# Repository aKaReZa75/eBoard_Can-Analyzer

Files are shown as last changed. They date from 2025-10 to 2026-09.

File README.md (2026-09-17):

# eBoard Can BUS Analyzer

This project is a **custom STM32-based CAN analyzer** designed to capture, monitor, and analyze **CAN BUS** traffic using **SavvyCAN** or any other compatible PC software.
It supports both **Classical CAN (2.0A/B)** and **CAN FD**, making it a flexible and powerful tool for vehicle diagnostics, reverse engineering, and data logging applications.

> [!NOTE]
This design is **based on the open-source Canable 2.0 project**, available at [https://canable.io/](https://canable.io/)

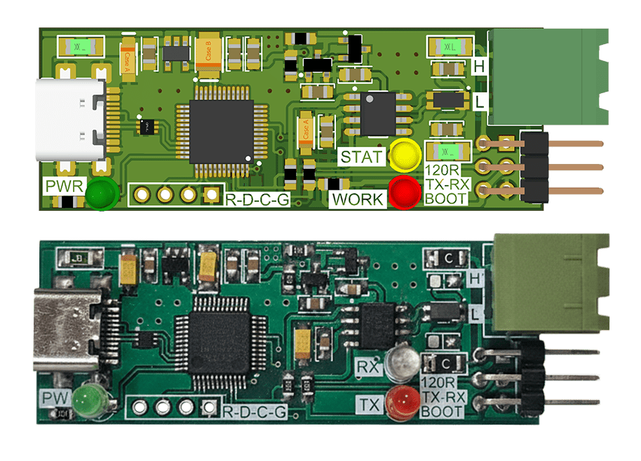
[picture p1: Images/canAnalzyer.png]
canAnalzyer


<table>
  <tr>
  <td valign="top">
  
  > [!TIP]  
  > If you're looking to better understand how to navigate and use my GitHub repositories — including exploring their structure, downloading or cloning projects, submitting issues, and asking questions,  
  > everything you need is clearly explained in this video:  
  > [aKaReZa 95 - Programming, Git - PART B](https://youtu.be/zYiUItVFRqQ)  
  > Make sure to check it out!
  
  </td>
    <td width="360" valign="middle" style="padding: 0;">
      <a href="https://youtu.be/zYiUItVFRqQ">
       aKaReZa 95 - Programming, Git - PART B Thumbnail
      </a>
    </td>
  </td>
  </tr>

<tr>
  <td valign="top">
  
  > [!IMPORTANT]
  > Begin your embedded systems journey with clarity and purpose. This episode outlines a structured roadmap for mastering microcontrollers, communication protocols, hardware design, and project development.  
  > Learn how to choose your specialization, follow curated playlists, and engage effectively with the community—ideal for learners seeking a scalable, goal-driven path into embedded engineering.  
  > [aKaReZa 124 – Embedded Systems Roadmap](https://youtu.be/3QYfv7A7aMc)  
  > Watch it now to kickstart your journey!
  
  </td>
  <td width="360" valign="middle" style="padding: 0;">
    <a href="https://youtu.be/3QYfv7A7aMc">
      aKaReZa 124 – Embedded Systems Roadmap Thumbnail
    </a>
  </td>
</tr>

  <tr>
  <td colspan="3">

  > [!CAUTION]
  > It is absolutely critical that you carefully read every single word of this document, line by line, to ensure you don't miss any details. Nothing can be overlooked.
      
  </td>
  </tr>  
</table>

##  Key Features
* **Dual CAN Protocol Support**
  Fully compatible with **CAN 2.0A/B** and **CAN FD** standards.

* **USB Interface with DFU Support**
  Built-in **DFU (Device Firmware Upgrade)** mode allows you to easily update firmware via USB — no external programmer needed.

* **Hardware Termination Control**
  Includes a dedicated **jumper** to enable or disable the **120 Ω termination resistor**, allowing flexible connection to different CAN networks.

* **Direct CAN TX/RX Monitoring Pins**
  The **TX** and **RX** lines of the CAN transceiver are **broken out** for use with a **logic analyzer**, enabling low-level signal observation and debugging.

* **Robust EMI Protection**
  The board integrates **EMI filters**, **common-mode chokes**, and **TVS diodes** on both the **USB** and **CAN** interfaces — ensuring reliable operation in noisy automotive environments.

* **Software Compatibility**
  Fully supported by **SavvyCAN**, **candleLight**, and any **SocketCAN-compatible** toolset on Windows, Linux, or macOS.

## Typical Use Cases
* Sniffing and analyzing automotive CAN frames
* Reverse-engineering vehicle signals (speed, RPM, etc.)
* Logging CAN data for diagnostics or visualization
* Testing and validating CAN-based ECUs and sensors
* Educational and research projects in automotive communication

## Firmware Recommendation
For best performance, it’s recommended to flash the **`CANable_2.0_SLCAN_FD_7-7-22.bin`** firmware onto the board.
You can program it using an external **programmer** (e.g., ST-Link) or update it directly through the **DFU bootloader** using standard DFU utilities or GUI tools.
This firmware provides full support for **CAN FD** and ensures stable communication with **SavvyCAN**, **Cangaroo**, and other compatible CAN analysis software.

## Technical Highlights
| Feature | Description |
| --- | --- |
| MCU | STM32G431C8T6 |
| CAN Support | CAN 2.0A/B and CAN FD |
| USB Mode | Full-Speed USB 2.0 |
| Firmware Update | DFU mode over USB |
| Software Support | Savvycan/Cangaroo |
| Termination | Selectable 120 Ω via jumper |
| Protection | EMI filter, TVS diodes, common-mode choke |
| Monitoring | TX/RX breakout for logic analyzer |
| Compatible Software | SavvyCAN, SocketCAN, BusMaster, etc. |
| PCB Design Software | Altium  V24.2.2 |
| PCB Layers | 2-Layer FR4 |

# 🔗 Resources
  Here you'll find a collection of useful links and videos related to this topic.  
  
> [!TIP]
> The resources are detailed in the sections below.  
> To access any of them, simply click on the corresponding blue link.

- [Altium Library](https://github.com/aKaReZa75/Altium-Library)  
  ---  
   All PCB designs across all repositories and projects are built using this Altium Designer component library. It contains a wide range of verified footprints, schematic symbols, and 3D models, ensuring consistency and accuracy in PCB designs. If you're working on a new PCB, using this library will save you time and minimize errors.

- [PCB & Electronics Design Training](https://github.com/aKaReZa75/PCB)  
  ---  
  This repository is dedicated to **learning PCB design and electronics from scratch**. It covers everything from circuit theory to practical PCB layout techniques, including routing strategies, best practices, and component placement. Whether you're a beginner or an experienced designer, this resource will help you **improve your PCB design skills and create professional-quality boards**.

- [Shopping Link](./ShoppingLink.md)  
  ---
  This document provides links to trusted suppliers where you can purchase all the essential components for this project, ensuring quality and reliability.

- [SavvyCAN](https://github.com/collin80/SavvyCAN)
  ---
  A powerful **cross-platform CAN bus capture and reverse engineering tool** built with **Qt/C++**.
  SavvyCAN supports a wide range of CAN interfaces (SocketCAN, PeakCAN, Vector, J2534, etc.) and allows simultaneous connection to multiple buses.
  It includes features for **graphing, decoding with DBC files, UDS scanning**, and analyzing complex CAN traffic efficiently.

- [Cangaroo](https://github.com/normaldotcom/cangaroo)
  ---
  An open-source **CAN bus analyzer** supporting **transmit/receive of standard and FD frames**, as well as **DBC decoding** for incoming data.
  It works seamlessly on **Windows** and **Linux** with any **CANable** device running **Candlelight** or **SLCAN** firmware.
  Cangaroo provides advanced features like DBC decoding, periodic frame transmission, and multi-interface auto-detection on startup.

## Project Videos

```plaintext
CAN BUS Analyzer
└─ [aKaReZa 141 - eBoard, CAN Analyzer]
      ├─ Design — Hardware architecture and schematic review.
      ├─ Assembly — PCB soldering and device bring-up.
      ├─ Firmware — Programming and initial configuration.
      ├─ Interface — Pinout and CAN connectivity.
      ├─ Analysis — Using SavvyCAN and Congroo.
      └─ Applications — CAN monitoring, debugging, and diagnostics.
```

<table style="border-collapse: collapse;">
  <tr style="background-color: #f9f9f9;">
    <td valign="top" style="padding: 0 10px;">
      <h3 style="margin: 0;">
        <a href="https://youtu.be/rj74_Sh1n9M">aKaReZa 141 – eBoard, CAN Analyzer</a>
      </h3>
      <p style="margin: 8px 0 0;">
        Learn how to design, assemble, and use a complete <strong>CAN Analyzer</strong> from scratch. This episode covers the hardware architecture, schematic review, PCB assembly, firmware programming, device pinout, and integration with tools like <strong>SavvyCAN</strong> and <strong>Congroo</strong> for CAN bus monitoring and analysis. A practical introduction for anyone interested in CAN network development, debugging, and diagnostics.
      </p>
    </td>
    <td width="360" valign="top">
      <a href="https://youtu.be/rj74_Sh1n9M">
        aKaReZa 43 – PCB, USB to TTL Thumbnail
      </a>
    </td>
  </tr>
</table>

# 💻 How to Use Git and GitHub
To access the repository files and save them on your computer, there are two methods available:
1. **Using Git Bash and Cloning the Repository**
   - This method is more suitable for advanced users and those familiar with command-line tools.
   - By using this method, you can easily receive updates for the repository.

2. **Downloading the Repository as a ZIP file**
   - This method is simpler and suitable for users who are not comfortable with command-line tools.
   - Note that with this method, you will not automatically receive updates for the repository and will need to manually download any new updates.

## Clone using the URL.
First, open **Git Bash** :
-  Open the folder in **File Explorer** where you want the library to be stored.
-  **Right-click** inside the folder and select the option **"Open Git Bash here"** to open **Git Bash** in that directory.

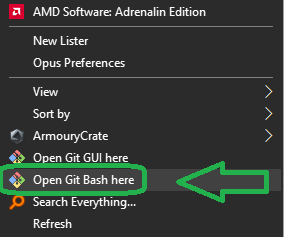
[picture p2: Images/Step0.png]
open Git Bash


> [!NOTE] 
> If you do not see the "Open Git Bash here" option, it means that Git is not installed on your system.  
> You can download and install Git from [this link](https://git-scm.com/downloads).  
> For a tutorial on how to install and use Git, check out [this video](https://youtu.be/BsykgHpmUt8).
  
-  Once **Git Bash** is open, run the following command to clone the repository:

 ```bash
git clone https://github.com/aKaReZa75/eBoard_Can-Analyzer.git
```
- You can copy the above command by either:
- Clicking on the **Copy** button on the right of the command.
- Or select the command text manually and press **Ctrl + C** to copy.
- To paste the command into your **Git Bash** terminal, use **Shift + Insert**.

Clone the Repository

- Then, press Enter to start the cloning operation and wait for the success message to appear.

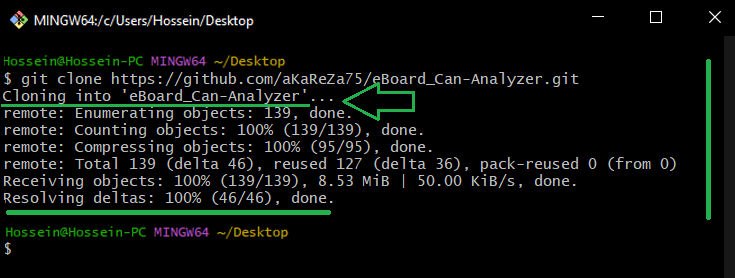
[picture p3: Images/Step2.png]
Open the Library File


> [!IMPORTANT]
> Please keep in mind that the numbers displayed in the image might vary when you perform the same actions.  
> This is because repositories are continuously being updated and expanded. Nevertheless, the overall process remains unchanged.

> [!NOTE]
> Advantage of Cloning the Repository:  
> - **Receiving Updates:** By cloning the repository, you can easily and automatically receive new updates.  
> - **Version Control:** Using Git allows you to track changes and revert to previous versions.  
> - **Team Collaboration:** If you are working on a project with a team, you can easily sync changes from team members and collaborate more efficiently.  

## Download Zip
If you prefer not to use Git Bash or the command line, you can download the repository directly from GitHub as a ZIP file.  
Follow these steps:  
1. Navigate to the GitHub repository page and Locate the Code button:
   - On the main page of the repository, you will see a green Code button near the top right corner.

2. Download the repository:
   - Click the Code button to open a dropdown menu.
   - Select Download ZIP from the menu.

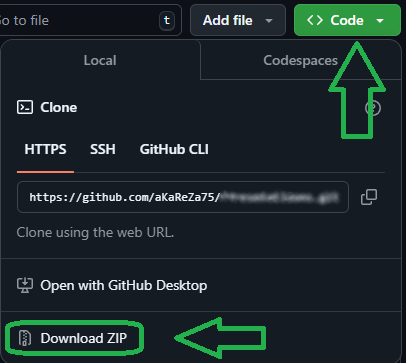
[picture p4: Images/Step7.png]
Download Zip
    

3. Save the ZIP file:
   - Choose a location on your computer to save the ZIP file and click Save.

4. Extract the ZIP file:
   - Navigate to the folder where you saved the ZIP file.
   - Right-click on the ZIP file and select Extract All... (Windows) or use your preferred extraction tool.
   - Choose a destination folder and extract the contents.

5. Access the repository:
   - Once extracted, you can access the repository files in the destination folder.

> [!IMPORTANT]
> - No Updates: Keep in mind that downloading the repository as a ZIP file does not allow you to receive updates.    
>   If the repository is updated, you will need to download it again manually.  
> - Ease of Use: This method is simpler and suitable for users who are not comfortable with Git or command-line tools.

# 📝 How to Ask Questions
If you have any questions or issues, you can raise them through the **"Issues"** section of this repository. Here's how you can do it:  

1. Navigate to the **"Issues"** tab at the top of the repository page.  

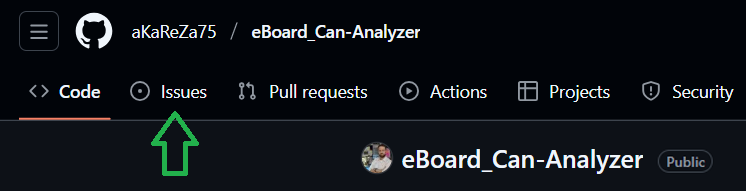
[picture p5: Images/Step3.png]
Issues
  

2. Click on the **"New Issue"** button.  
   
  New Issue

3. In the **Title** field, write a short summary of your issue or question.  

4. In the "Description" field, detail your question or issue as thoroughly as possible. You can use text formatting, attach files, and assign the issue to someone if needed. You can also use text formatting (like bullet points or code snippets) for better readability.  

5. Optionally, you can add **labels**, **type**, **projects**, or **milestones** to your issue for better categorization.  

6. Click on the **"Submit new issue"** button to post your question or issue.
   
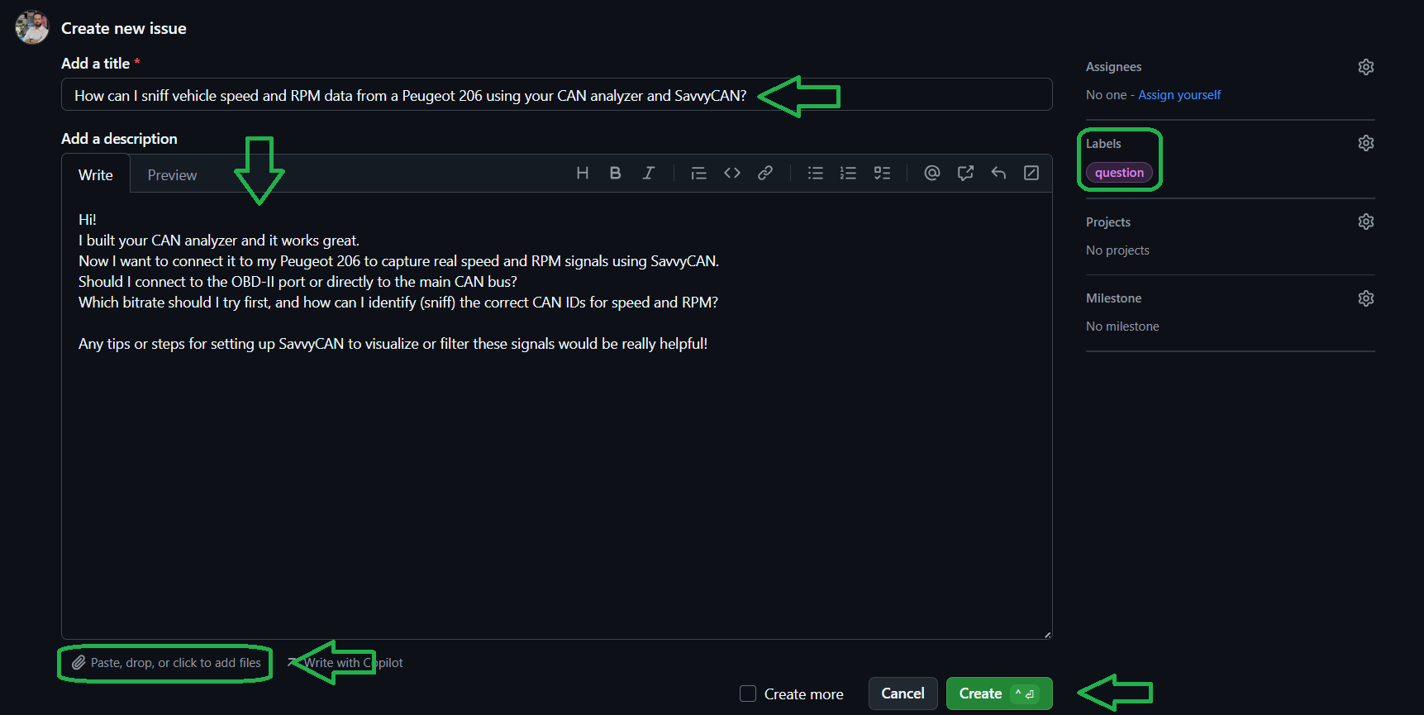
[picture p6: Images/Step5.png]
Submeet New Issue
  

I will review and respond to your issue as soon as possible. Your participation helps improve the repository for everyone!  

> [!TIP]
> - Before creating a new issue, please check the **"Closed"** section to see if your question has already been answered.  
>   Closed section  
> - Write your question clearly and respectfully to ensure a faster and better response.  
> - While the examples provided above are in English, feel free to ask your questions in **Persian (فارسی)** as well.  
> - There is no difference in how they will be handled!  

> [!NOTE]
> Pages and interfaces may change over time, but the steps to create an issue generally remain the same.

# 🤝 Contributing to the Repository
To contribute to this repository, please follow these steps:
1. **Fork the Repository**  
2. **Clone the Forked Repository**  
3. **Create a New Branch**  
4. **Make Your Changes**  
5. **Commit Your Changes**  
6. **Push Your Changes to Your Forked Repository**  
7. **Submit a Pull Request (PR)**  

> [!NOTE]
> Please ensure your pull request includes a clear description of the changes you’ve made.
> Once submitted, I will review your contribution and provide feedback if necessary.

# 🌟 Support Me
If you found this repository useful:
- Subscribe to my [YouTube Channel](https://www.youtube.com/@aKaReZa75).
- Share this repository with others.
- Give this repository and my other repositories a star.
- Follow my [GitHub account](https://github.com/aKaReZa75).

# 📜 License
This project is licensed under the GPL-3.0 License. This license grants you the freedom to use, modify, and distribute the project as long as you:
- Credit the original authors: Give proper attribution to the original creators.
- Disclose source code: If you distribute a modified version, you must make the source code available under the same GPL license.
- Maintain the same license: When you distribute derivative works, they must be licensed under the GPL-3.0 too.
- Feel free to use it in your projects, but make sure to comply with the terms of this license.
  
# ✉️ Contact Me
Feel free to reach out to me through any of the following platforms:
- 📧 [Email: aKaReZa75@gmail.com](mailto:aKaReZa75@gmail.com)
- 🎥 [YouTube: @aKaReZa75](https://www.youtube.com/@aKaReZa75)
- 💼 [LinkedIn: @akareza75](https://www.linkedin.com/in/akareza75)

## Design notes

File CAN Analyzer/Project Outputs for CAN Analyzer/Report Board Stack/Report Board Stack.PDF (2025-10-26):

# Board Stack Report

Stack Up | Layer Stack
Layer | Board Layer Stack | Name | Material | Thickness | Constant | Dk | Coverlay expansion | Orientation | Copper Orientation
1 | | Top Overlay | | 0mm
2 | | Top Solder | Solder Resist | 0.01016mm | 3.5 | 3.5 0mm
3 | | Top Layer | | 0.03556mm | | | | BodyUp | Above
4 | | Dielectric 1 | FR-4 | 1.5mm | 4.8 | 4.8
5 | | Bottom Layer | | 0.03556mm | | | | BodyDown | Below
6 | | Bottom Solder | Solder Resist | 0.01016mm | 3.5 | 3.5 0mm
7 | | Bottom Overlay | | 0mm
| Height : 1.59144mm

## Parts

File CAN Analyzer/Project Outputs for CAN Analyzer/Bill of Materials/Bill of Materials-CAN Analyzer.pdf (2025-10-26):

Comment | Description | Designator | Footprint | LibRef | Quantity | Value | Type | Rating | Inflow | Package
100n | Bipolar ceramic capacitor SMD | C2, C4, C6, C7, C14, C15 | CAP 0805/2012 | Cap_Multi_SMD_100nF _0805 | 6 | 100n | MultiLayer | 50V | inflow? | 0805
10u | Bipolar ceramic capacitor SMD | C13 | CAP 0805/2012 | Cap_Multi_SMD_0805 | 1 | 10u | MultiLayer | Rating? | inflow? | 0805
47p | Bipolar ceramic capacitor SMD | C16, C17 | CAP 0805/2012 | Cap_Multi_SMD_0805 | 2 | 47p | MultiLayer | Rating? | inflow? | 0805
4u7 | Tantalum Capacitor,TAJ Series-SMD | C3 | SMT_C_Tantalum_A | Cap_Tantalum | 1 | 4u7 | Tantalum | 6.3V | inflow? | SMD-A
10u | Tantalum Capacitor,TAJ Series-SMD | C1 | SMT_C_Tantalum_A | Cap_Tantalum | 1 | 10u | Tantalum | 6V3 | inflow? | Package?
10u | Tantalum Capacitor,TAJ Series-SMD | C5 | SMT_C_Tantalum_B | Cap_Tantalum | 1 | 10u | Tantalum | 6V3 | inflow? | Package?
3x2 | Header, dual row, 6 pin | J3 | HDR_THT_3x2M_2.54m m_RA | Con_MPH_3x2_V_THT_ 2.54 | 1 | 3x2 | Type? | Rating? | 7152 | Package?
4b | Header, single row, 4 pin | J2 | HDR_THT_4M_2.54mm | Con_MPH_4x1_V_THT_ 2.54 | 1 | 4b | Vertical | 4x1 | 7152 | Dip
2'Pin | Power Connector 2'Pin | P1 | Phoenix_2PIN_RA_P5.0 8mm | Con_Power_2 | 1 | 2'Pin | Type? | Rating? | inflow? | Package?
16P | USB C Female Connector | J1 | USBC_SMD_16_USB41 10 - Extended | Con_USB_C_16P | 1 | 16P | C | Rating? | inflow? | SMD
TJA1051T-3 | High-Speed CAN Transceiver That Provides an Interface Between a CAN Protocol Controller and The Physical Two-Wire CAN Bus. | U1 | SO8_narrow_M | IC_Converter_TJA1051 T-3 | 1 | TJA1051T-3 | CAN-FD | 5Mbits/s | inflow? | SOIC-8
STM32G431C8T6 | 32-Bit mircrocontroller | U3 | LQFP48_N | IC_MCU_STM32G431C 8T6 | 1 | STM32G431C8T6 | Microcontroller | CORTEX-M4 | inflow? | LQFP48
3.3V | Fixed LDO Voltage Regulator 3.3V 300mA SOT-23-5 | U2 | SOT95P280X130-5N | IC_Reg_TLV74333PDBV R | 1 | 3.3V | LDO | 300m | inflow? | SOT-23-5
Value? | 2 Line Common Mode Choke Surface Mount 90 Ohms @ 100 MHz 370mA DCR 300mOhm | L1 | FIL_DLW31SN900SQ2L _Extended | Ind_EMI_DLW31SN900 SQ2L | 1 | Value? | Type? | Rating? | inflow? | Package?
ECMF02-2AMX6 | Common Mode Filter with ESD Protection for USB 2.0 and MIPI D-PHY/MDDI Interface | L2 | SON50P150X170X55-6N | Ind_EMI_ECMF02-2AMX6 | 1 | ECMF02-2AMX6 | EMI Filters | 2.5R | | QFN-6
250m | Short circiut protection | F3 | 1206_F | Other_Elec_Fuse_SMD | 1 | 250m | Fast | Rating? | 0.5A | 1206
200m | SMD Resettable Fuses | F1, F2 | 1206_F | Other_Elec_PFUSE_SM D | 2 | 200m | Resettable | 24V | inflow? | 1206
1M | Resistor | R13 | RES 0805 (2012X06L) | Res_SMD_0805 | 1 | 1M | 10% | 0.125W | inflow? | 0805
4K7 | Resistor | R4, R5, R10, R14 | RES 0805 (2012X06L) | Res_SMD_0805 | 4 | 4K7 | 10% | 0.125W | inflow? | 0805
10K | Resistor | R9, R16 | RES 0805 (2012X06L) | Res_SMD_0805 | 2 | 10K | 10% | 0.125W | inflow? | 0805
22R | Resistor | R1, R2 | RES 0805 (2012X06L) | Res_SMD_0805 | 2 | 22R | 10% | 0.125W | inflow? | 0805
47K | Resistor | R11, R15 | RES 0805 (2012X06L) | Res_SMD_0805 | 2 | 47K | 10% | 0.125W | inflow? | 0805
100K | Resistor | R12 | RES 0805 (2012X06L) | Res_SMD_0805 | 1 | 100K | 10% | 0.125W | inflow? | 0805
120R | Resistor | R3 | RES 0805 (2012X06L) | Res_SMD_0805 | 1 | 120R | 1% | 0.125W | inflow? | 0805
330R | Resistor | R6, R7, R8 | RES 0805 (2012X06L) | Res_SMD_0805 | 3 | 330R | 10% | 0.125W | inflow? | 0805
BC817 | NPN General purpose Transistor | Q3, Q4 | SOT23_N | Semi_BJT_BC817 | 2 | BC817 | NPN | Rating? | inflow? | Package?
NPN | NPN General purpose Transistor | Q2 | SOT23_N | Semi_BJT_SS8050 | 1 | NPN | Type? | Rating? | 5256 | Package?
SM712 | TVS, ESD PROTECT, 2CH, 400W/17A PP, 7.5VBR, ±8KV ESDmin | D1 | SOT23_M | Semi_Diod_TVS_SM71 2 | 1 | SM712 | Type? | Rating? | inflow? | Package?
Green, 3'mm | LED | D3 | led-3mm | Semi_LED_Green_3 | 1 | Green, 3'mm | Type? | Rating? | 7145 | Package?
Red, 3'mm | LED | D4 | LED-3mm(RED) | Semi_LED_Red_3 | 1 | Red, 3'mm | Type? | Rating? | 7142 | Package?
Yellow | LED | D2 | LED-3mm_Yellow | Semi_LED_Yellow_3 | 1 | Yellow | LED | Rating? | 7145 | 3mm
P-Channel | P-Channel MOSFET | Q1 | SOT23_N | Semi_MOSFET_Si2301 DS | 1 | P-Channel | Type? | Rating? | 6208 | Package?

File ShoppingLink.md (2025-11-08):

# 📦 Components Purchase Links
This section provides a comprehensive list of components required for the "CAN BUS Analyzer" project.
Each item includes direct purchase links from reliable Iranian electronics suppliers, with recommended quantities for both essential needs and future prototyping.

## Capacitor
- [ ] [**Cap_0805 47p**](https://lionelectronic.ir/products/1952-0805CG470J500NT) Quantity: 4, Prefer: 25, Supplier: LionElectronic
- [ ] [**Cap_0805_100n**](https://lionelectronic.ir/products/2791-CL21B104KBCNNNC) Quantity: 8, Prefer: 25, Supplier: LionElectronic
- [ ] [**Cap_0805_10u**](https://lionelectronic.ir/products/3069-C2012X5R1H106K125AC) Quantity: 8, Prefer: 25, Supplier: LionElectronic
- [ ] [**Cap_Tantal_4.7u_6.3V_P**](https://lionelectronic.ir/products/2725-T55P475M6R3C0500) Quantity: 1, Prefer: 10, Supplier: LionElectronic 
- [ ] [**Cap_Tantal_10u_10V_A**](https://lionelectronic.ir/products/2046-TAJA106K010RNJ) Quantity: 3, Prefer: 10, Supplier: LionElectronic **(Instead of: Cap_Tantal_10u_6.3V_A)**

## Connector
- [ ] [**Male_PinHeader_Straight**](https://lionelectronic.ir/products/5356-PLS-2.54-1X40GF) Quantity: 0.1, Prefer: 1, Supplier: LionElectronic
- [ ] [**Male_PinHeader_Right_Double**](https://lionelectronic.ir/products/5359-DS1022-2X40R-1) Quantity: 0.1, Prefer: 1, Supplier: LionElectronic  
- [ ] [**Con_Phonix_2Pin**](https://lionelectronic.ir/products/6049-KF2EDGR%2BK-5.08-2P) Quantity: 2, Prefer: 5, Supplier: LionElectronic
- [ ] [**USB_Type_C_16_2**](https://lionelectronic.ir/products/4117-TYPE-C-16P-QTWT) Quantity: 1, Prefer: 4, Supplier: LionElectronic

## Integrated Circuit
- [ ] [**IC_STM32G431C8T6**](https://lionelectronic.ir/products/2774-STM32G431C8T6) Quantity: 1, Prefer: 3, Supplier: LionElectronic  
- [ ] [**Reg_TLV74333PDBVR**](https://lionelectronic.ir/products/2492-TLV74333PDBVR) Quantity: 1, Prefer: 3, Supplier: LionElectronic
- [ ] [**IC_TJA1051T/3,118**](https://lionelectronic.ir/products/5827-TJA1051T-3%2C118) Quantity: 1, Prefer: 5, Supplier: LionElectronic

## Other
- [ ] [**DLW31SN900SQ2L**](https://lionelectronic.ir/products/1500-DLW31SN900SQ2L) Quantity: 2, Prefer: 5, Supplier: LionElectronic
- [ ] [**ECMF02-2AMX6**](https://lionelectronic.ir/products/4373-ECMF02-2AMX6) Quantity: 2, Prefer: 5, Supplier: LionElectronic
- [ ] [**Fuse_1206_0.5A**](https://lionelectronic.ir/products/1891-JFC1206-0500FS-63V-0.5A) Quantity: 1, Prefer: 5, Supplier: LionElectronic  
- [ ] [**rFuse_1206_0.2A**](https://lionelectronic.ir/products/2259-1206L020YR) Quantity: 1, Prefer: 5, Supplier: LionElectronic

## Resistor
- [ ] [**Res_0805_22b**](https://lionelectronic.ir/products/1553-0805W8J0220T5E) Quantity: 3, Prefer: 25, Supplier: LionElectronic
- [ ] [**Res_0805_120R_1%**](https://lionelectronic.ir/products/1404-CR0805F81200G) Quantity: 2, Prefer: 25, Supplier: LionElectronic  
- [ ] [**Res_0805_330b**](https://lionelectronic.ir/products/1567-SER0805J330R) Quantity: 5, Prefer: 25, Supplier: LionElectronic
- [ ] [**Res_0805_1K**](https://lionelectronic.ir/products/1573-RS-05K102JT) Quantity: 3, Prefer: 25, Supplier: LionElectronic  
- [ ] [**Res_0805_4.7K**](https://lionelectronic.ir/products/1581-SER0805J4K7) Quantity: 4, Prefer: 25, Supplier: LionElectronic 
- [ ] [**Res_0805_10K**](https://lionelectronic.ir/products/1585-SCR0805J10K) Quantity: 2, Prefer: 25, Supplier: LionElectronic
- [ ] [**Res_0805_47K**](https://lionelectronic.ir/products/1593-SER0805J47K) Quantity: 2, Prefer: 25, Supplier: LionElectronic
- [ ] [**Res_0805_100K**](https://lionelectronic.ir/products/1474-RS-05K1003FT) Quantity: 2, Prefer: 25, Supplier: LionElectronic
- [ ] [**Res_0805_1M**](https://lionelectronic.ir/products/1609-0805W8J0105T5E) Quantity: 1, Prefer: 25, Supplier: LionElectronic

## Semiconductore
- [ ] [**Semi_BJT_BC817**](https://lionelectronic.ir/products/134-BC817-40) Quantity: 2, Prefer: 10, Supplier: LionElectronic
- [ ] [**Semi_Mosfet_Si2301**](https://www.javanelec.com/shop/product/17001/vishay/si2301ds-t1) Quantity: 7, Prefer: 25, Supplier: JavanElectronic
- [ ] [**Semi_Diod_TVS_SM712**](https://lionelectronic.ir/products/113-SM712.TCT) Quantity: 1, Prefer: 5, Supplier: LionElectronic 
- [ ] [**LED_3mm_Red**](https://lionelectronic.ir/products/3245-XL-304SURC) Quantity: 4, Prefer: 10, Supplier: LionElectronic
- [ ] [**LED_3mm_Green**](https://lionelectronic.ir/products/3244-XL-304UGC) Quantity: 4, Prefer: 10, Supplier: LionElectronic
- [ ] [**LED_3mm_Yellow**](https://lionelectronic.ir/products/3247-XL-304UYC) Quantity: 4, Prefer: 10, Supplier: LionElectronic

# 🌟 Support Me
If you found this repository useful:
- Subscribe to my [YouTube Channel](https://www.youtube.com/@aKaReZa75).
- Share this repository with others.
- Give this repository and my other repositories a star.
- Follow my [GitHub account](https://github.com/aKaReZa75).

# ✉️ Contact Me
Feel free to reach out to me through any of the following platforms:
- 📧 [Email: aKaReZa75@gmail.com](mailto:aKaReZa75@gmail.com)
- 🎥 [YouTube: @aKaReZa75](https://www.youtube.com/@aKaReZa75)
- 💼 [LinkedIn: @akareza75](https://www.linkedin.com/in/akareza75)

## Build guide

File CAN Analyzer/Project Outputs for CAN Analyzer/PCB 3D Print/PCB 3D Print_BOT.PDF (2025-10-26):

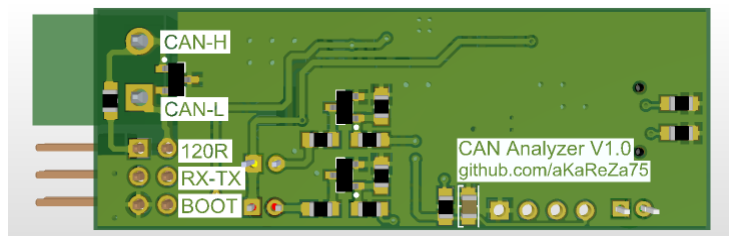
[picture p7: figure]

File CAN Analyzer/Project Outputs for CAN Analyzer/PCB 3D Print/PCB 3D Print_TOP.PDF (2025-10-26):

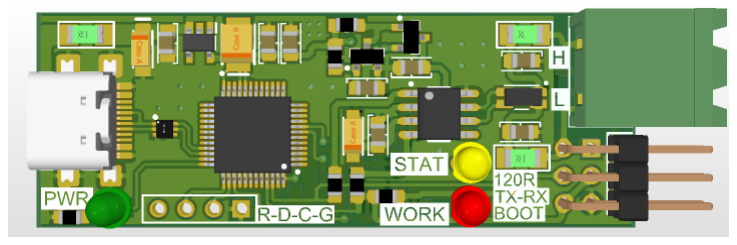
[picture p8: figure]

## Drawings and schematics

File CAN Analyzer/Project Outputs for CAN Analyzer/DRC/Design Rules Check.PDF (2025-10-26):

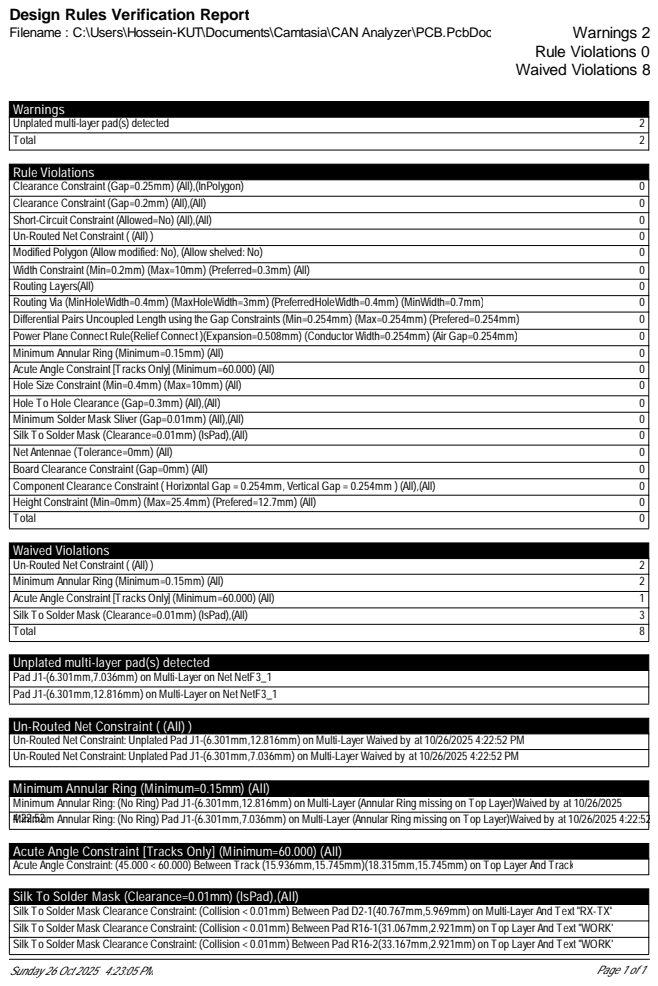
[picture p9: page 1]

Design Rules Verification Report

Unplated multi-layer pad(s) detected
Pad J1-(6.301mm,7.036mm) on Multi-Layer on Net NetF3_1
Pad J1-(6.301mm,12.816mm) on Multi-Layer on Net NetF3_1

Un-Routed Net Constraint ( (All) )
Un-Routed Net Constraint: Unplated Pad J1-(6.301mm,12.816mm) on Multi-Layer Waived by at 10/26/2025 4:22:52 PM
Un-Routed Net Constraint: Unplated Pad J1-(6.301mm,7.036mm) on Multi-Layer Waived by at 10/26/2025 4:22:52 PM

Minimum Annular Ring (Minimum=0.15mm) (All)
Minimum Annular Ring: (No Ring) Pad J1-(6.301mm,12.816mm) on Multi-Layer (Annular Ring missing on Top Layer)Waived by at 10/26/2025

M:2in2im:52um Annular Ring: (No Ring) Pad J1-(6.301mm,7.036mm) on Multi-Layer (Annular Ring missing on Top Layer)Waived by at 10/26/2025 4:22:52

Acute Angle Constraint [Tracks Only] (Minimum=60.000) (All)
Acute Angle Constraint: (45.000 < 60.000) Between Track (15.936mm,15.745mm)(18.315mm,15.745mm) on Top Layer And Track

Silk To Solder Mask (Clearance=0.01mm) (IsPad),(All)
Silk To Solder Mask Clearance Constraint: (Collision < 0.01mm) Between Pad D2-1(40.767mm,5.969mm) on Multi-Layer And Text "RX-TX"
Silk To Solder Mask Clearance Constraint: (Collision < 0.01mm) Between Pad R16-1(31.067mm,2.921mm) on Top Layer And Text "WORK"
Silk To Solder Mask Clearance Constraint: (Collision < 0.01mm) Between Pad R16-2(33.167mm,2.921mm) on Top Layer And Text "WORK"

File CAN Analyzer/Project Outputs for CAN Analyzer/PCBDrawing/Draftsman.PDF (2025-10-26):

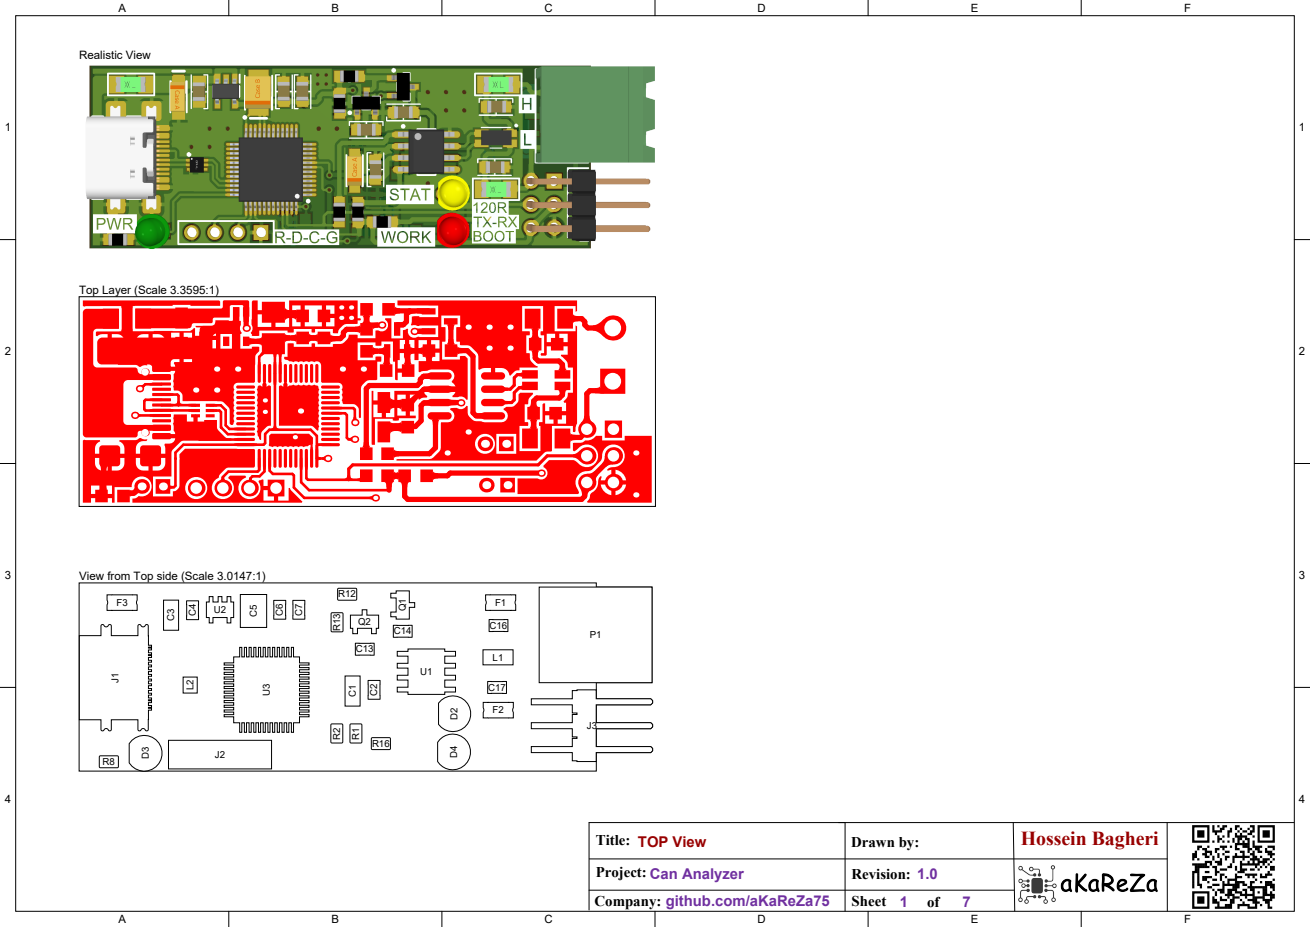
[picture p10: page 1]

View from Top side (Scale 3.0147:1)

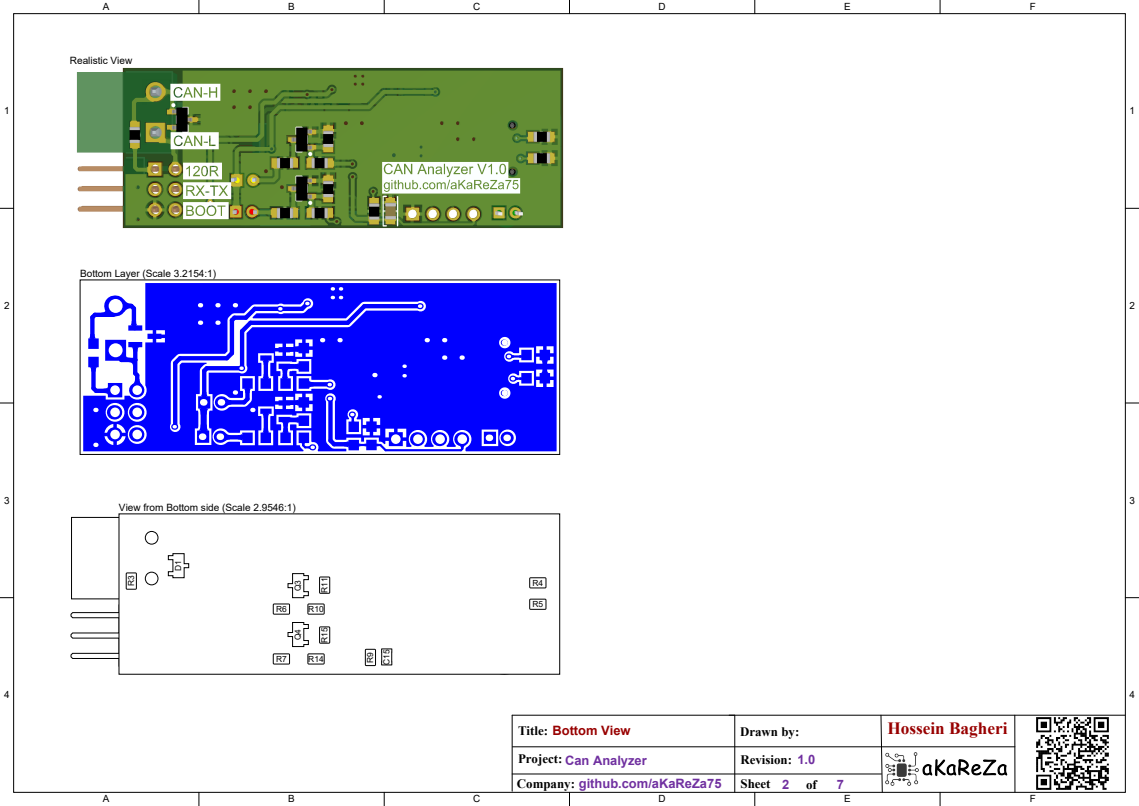
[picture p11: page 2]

View from Bottom side (Scale 2.9546:1)

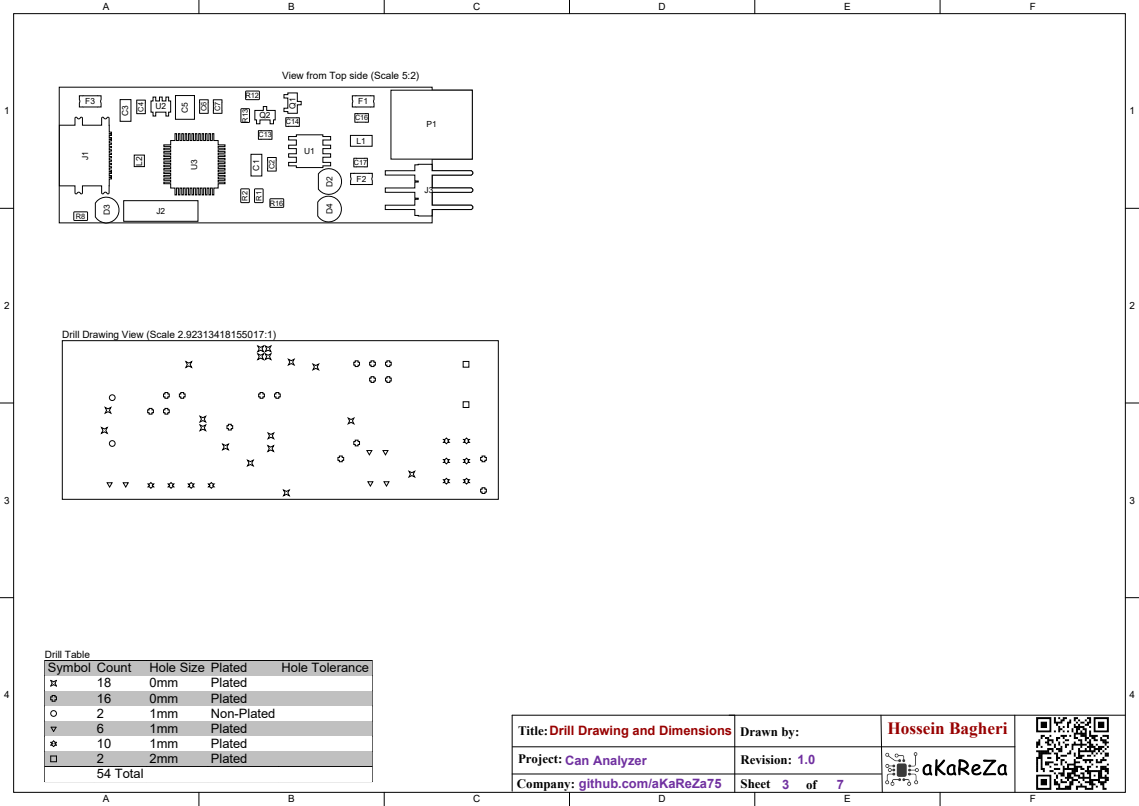
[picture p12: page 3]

View from Top side (Scale 5:2)

Drill Drawing View (Scale 2.92313418155017:1)

Symbol | Count | Hole Size | Plated | Hole Tolerance

18 | 0mm | Plated
16 | 0mm | Plated
2 | 1mm | Non-Plated
6 | 1mm | Plated
10 | 1mm | Plated
2 | 2mm | Plated
54 Total

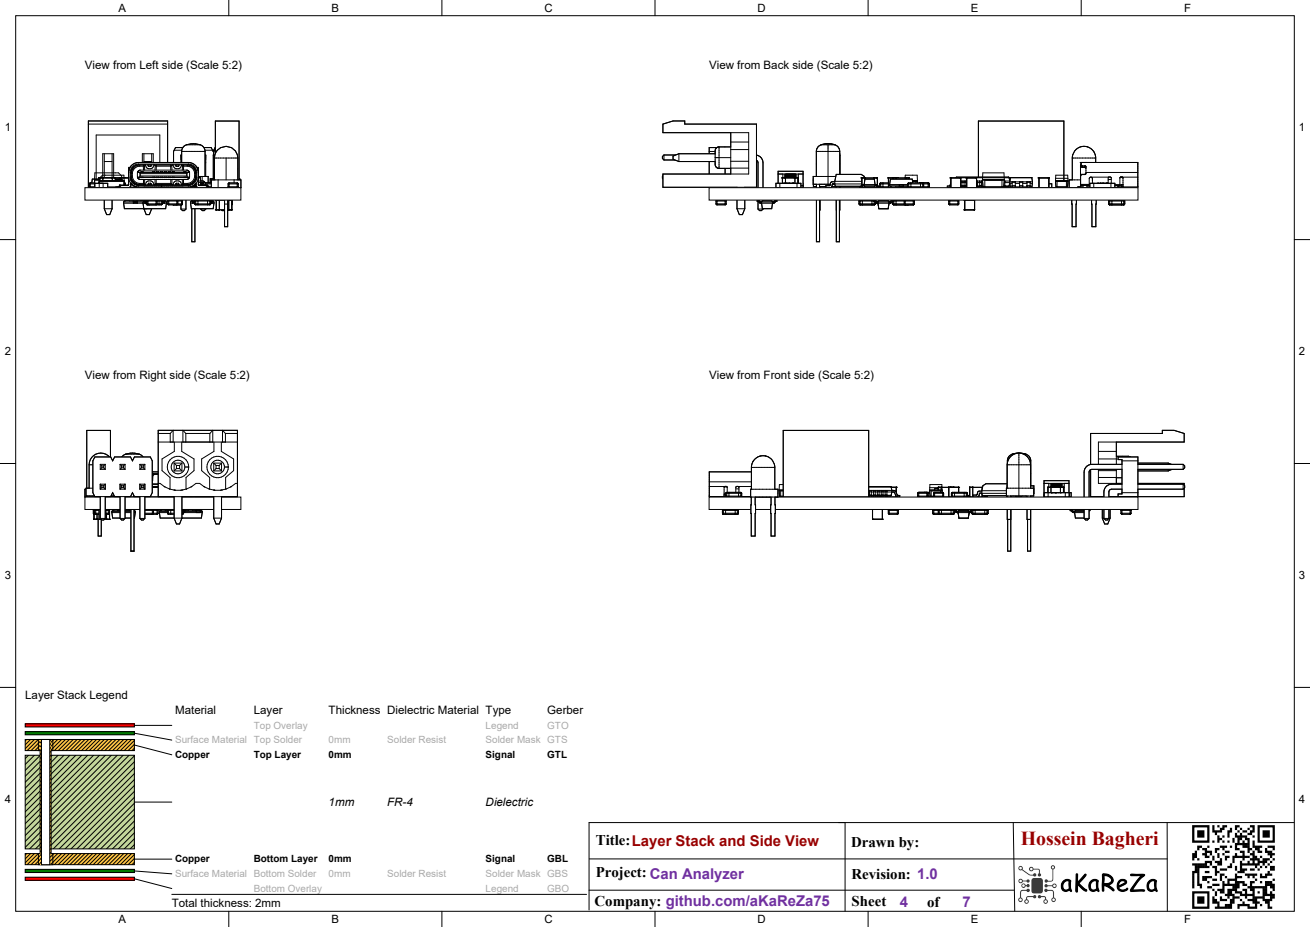
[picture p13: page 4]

View from Left side (Scale 5:2)

View from Back side (Scale 5:2)

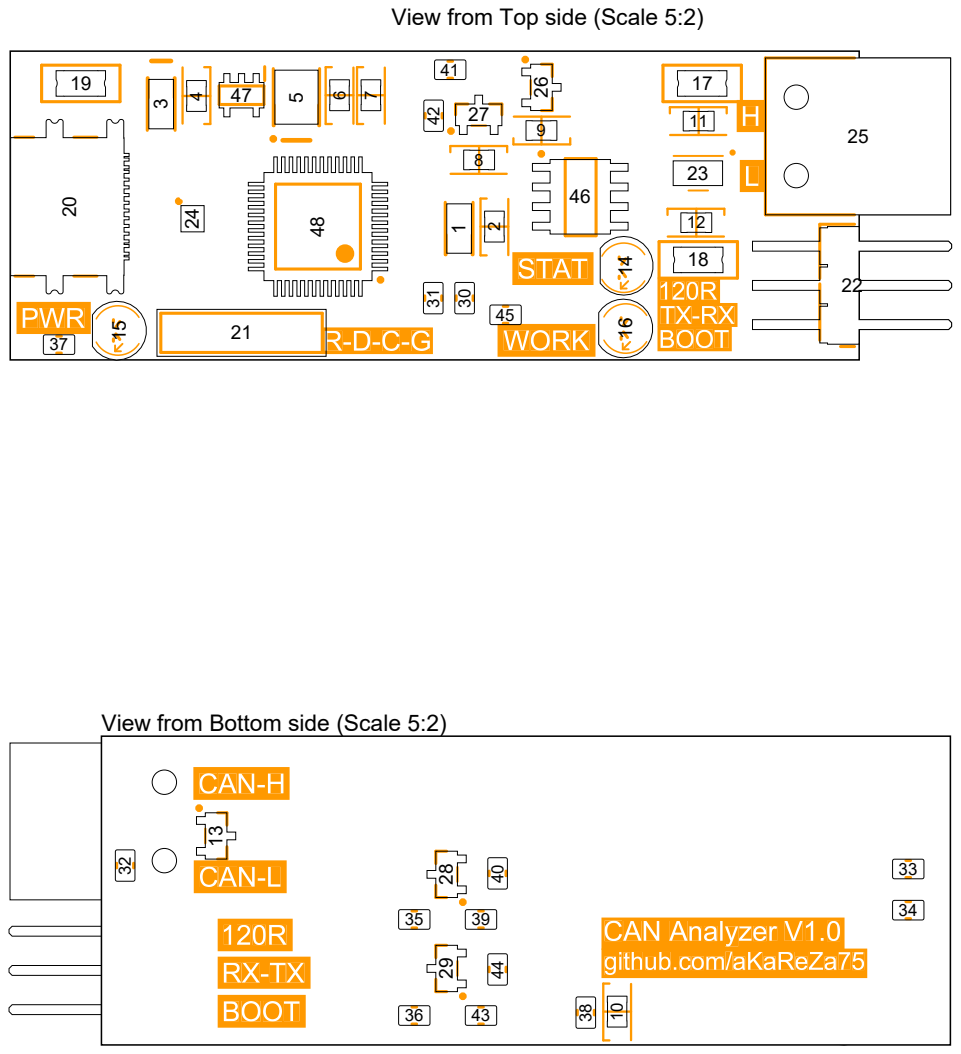
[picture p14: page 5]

View from Top side (Scale 5:2)

View from Bottom side (Scale 5:2)

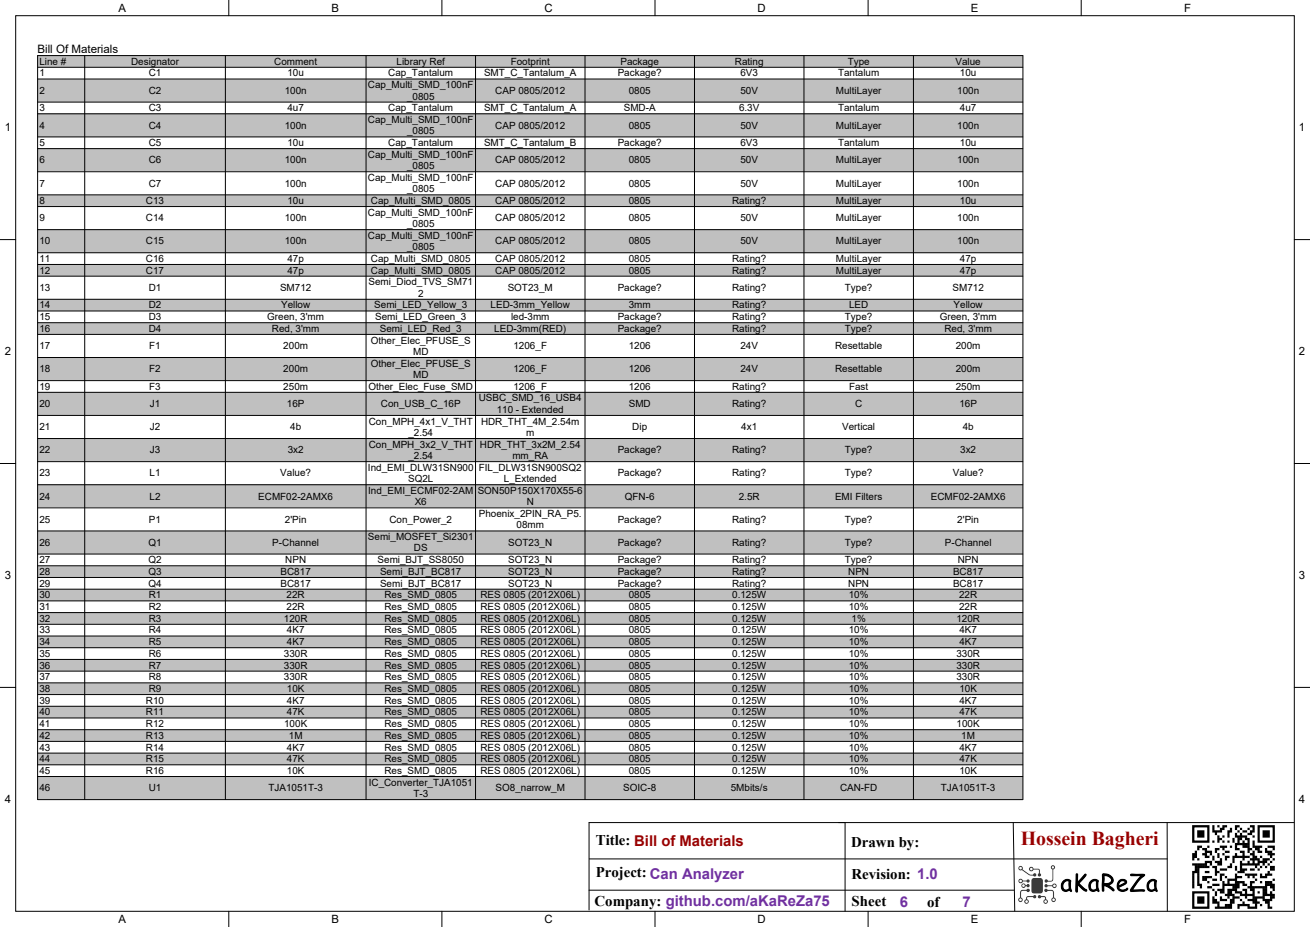
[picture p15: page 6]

Line # 123456789 | C3 | 4u7 | Cap_Tantalum | SMT_C_Tantalum_A | SMD-A | 6.3V | Tantalum | 4u7

Designator | Comment | Library Ref | Footprint | Package | Rating | Type | Value
C1 | 10u | Cap_Tantalum | SMT_C_Tantalum_A | Package? | 6V3 | Tantalum | 10u
C2 | 100n | Cap_Multi_SMD_100nF _0805 | CAP 0805/2012 | 0805 | 50V | MultiLayer | 100n

C4 | 100n | Cap_Multi_SMD_100nF _0805 | CAP 0805/2012 | 0805 | 50V | MultiLayer | 100n

C5 | 10u | Cap_Tantalum | SMT_C_Tantalum_B | Package? | 6V3 | Tantalum | 10u
C6 | 100n | Cap_Multi_SMD_100nF _0805 | CAP 0805/2012 | 0805 | 50V | MultiLayer | 100n

C7 | 100n | Cap_Multi_SMD_100nF _0805 | CAP 0805/2012 | 0805 | 50V | MultiLayer | 100n

C13 | 10u | Cap_Multi_SMD_0805 | CAP 0805/2012 | 0805 | Rating? | MultiLayer | 10u
C14 | 100n | Cap_Multi_SMD_100nF _0805 | CAP 0805/2012 | 0805 | 50V | MultiLayer | 100n

10 | C15 | 100n | Cap_Multi_SMD_100nF _0805 | CAP 0805/2012 | 0805 | 50V | MultiLayer | 100n

11 | C16 | 47p | Cap_Multi_SMD_0805 | CAP 0805/2012 | 0805 | Rating? | MultiLayer | 47p
12 | C17 | 47p | Cap_Multi_SMD_0805 | CAP 0805/2012 | 0805 | Rating? | MultiLayer | 47p
13 | D1 | SM712 | Semi_Diod_TVS_SM71 2 | SOT23_M | Package? | Rating? | Type? | SM712

14 | D2 | Yellow | Semi_LED_Yellow_3 | LED-3mm_Yellow | 3mm | Rating? | LED | Yellow
15 | D3 | Green, 3'mm | Semi_LED_Green_3 | led-3mm | Package? | Rating? | Type? | Green, 3'mm
16 | D4 | Red, 3'mm | Semi_LED_Red_3 | LED-3mm(RED) | Package? | Rating? | Type? | Red, 3'mm
17 | F1 | 200m | Other_Elec_PFUSE_S MD | 1206_F | 1206 | 24V | Resettable | 200m

18 | F2 | 200m | Other_Elec_PFUSE_S MD | 1206_F | 1206 | 24V | Resettable | 200m

19 | F3 | 250m | Other_Elec_Fuse_SMD | 1206_F | 1206 | Rating? | Fast C | 250m
20 | J1 | 16P | Con_USB_C_16P | USBC_SMD_16_USB4 110 - Extended | SMD | Rating? | | 16P

21 | J2 | 4b | Con_MPH_4x1_V_THT _2.54 | HDR_THT_4M_2.54m m | Dip | 4x1 | Vertical | 4b

22 | J3 | 3x2 | Con_MPH_3x2_V_THT _2.54 | HDR_THT_3x2M_2.54 mm_RA | Package? | Rating? | Type? | 3x2

23 | L1 | Value? | Ind_EMI_DLW31SN900 SQ2L | FIL_DLW31SN900SQ2 L_Extended | Package? | Rating? | Type? | Value?

24 | L2 | ECMF02-2AMX6 | Ind_EMI_ECMF02-2AM X6 | SON50P150X170X55-6 N | QFN-6 | 2.5R | EMI Filters | ECMF02-2AMX6

25 | P1 | 2'Pin | Con_Power_2 | Phoenix_2PIN_RA_P5. 08mm | Package? | Rating? | Type? | 2'Pin

26 | Q1 | P-Channel | Semi_MOSFET_Si2301 DS | SOT23_N | Package? | Rating? | Type? | P-Channel
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

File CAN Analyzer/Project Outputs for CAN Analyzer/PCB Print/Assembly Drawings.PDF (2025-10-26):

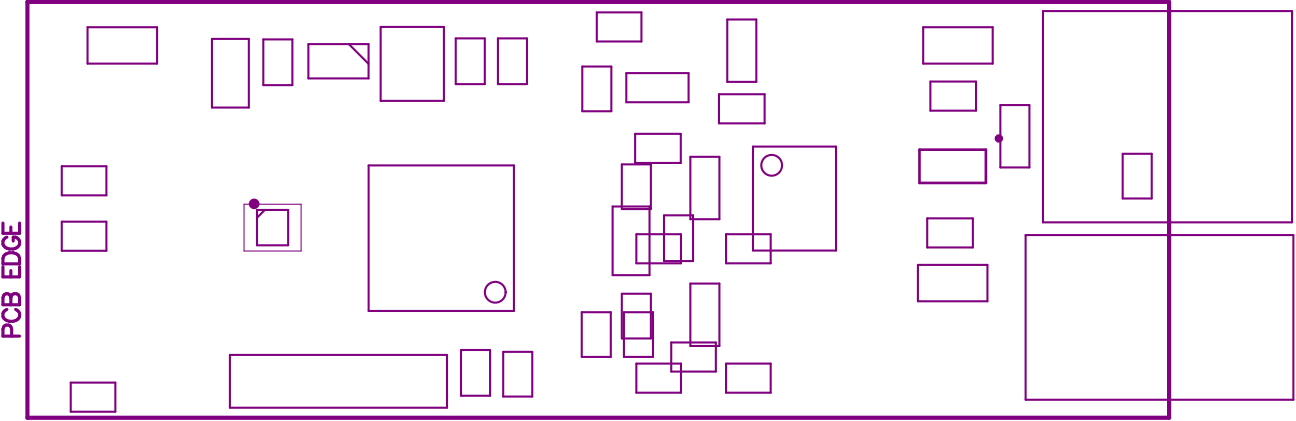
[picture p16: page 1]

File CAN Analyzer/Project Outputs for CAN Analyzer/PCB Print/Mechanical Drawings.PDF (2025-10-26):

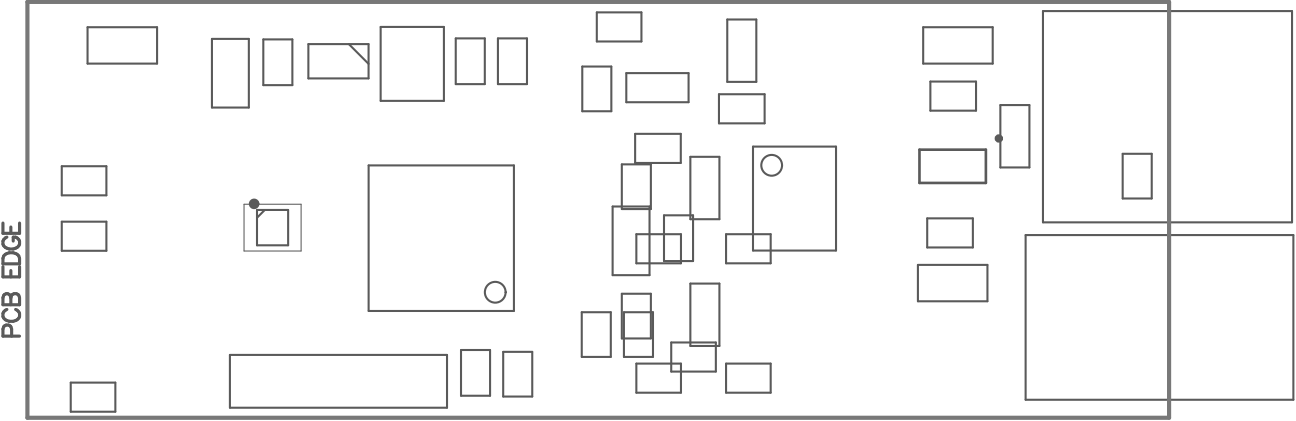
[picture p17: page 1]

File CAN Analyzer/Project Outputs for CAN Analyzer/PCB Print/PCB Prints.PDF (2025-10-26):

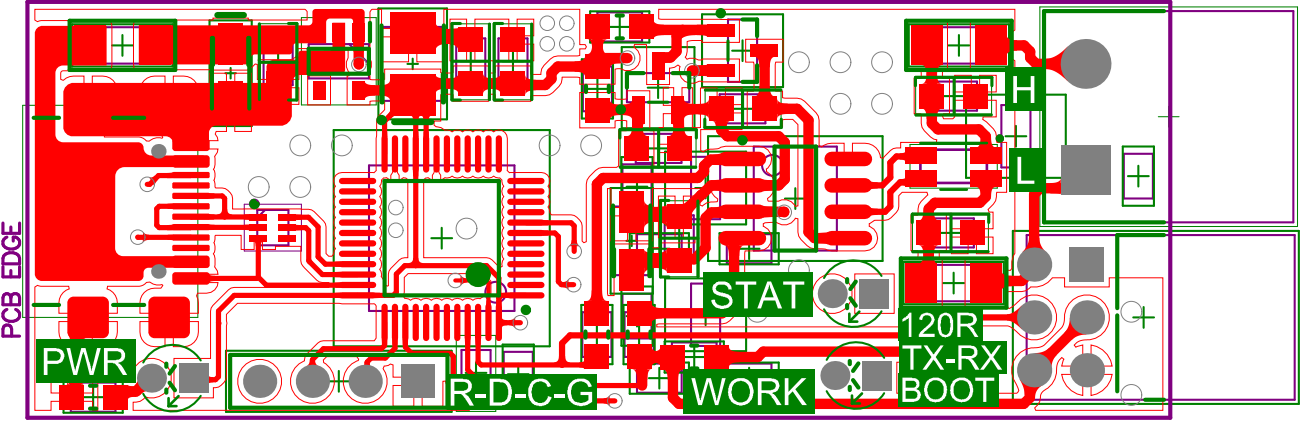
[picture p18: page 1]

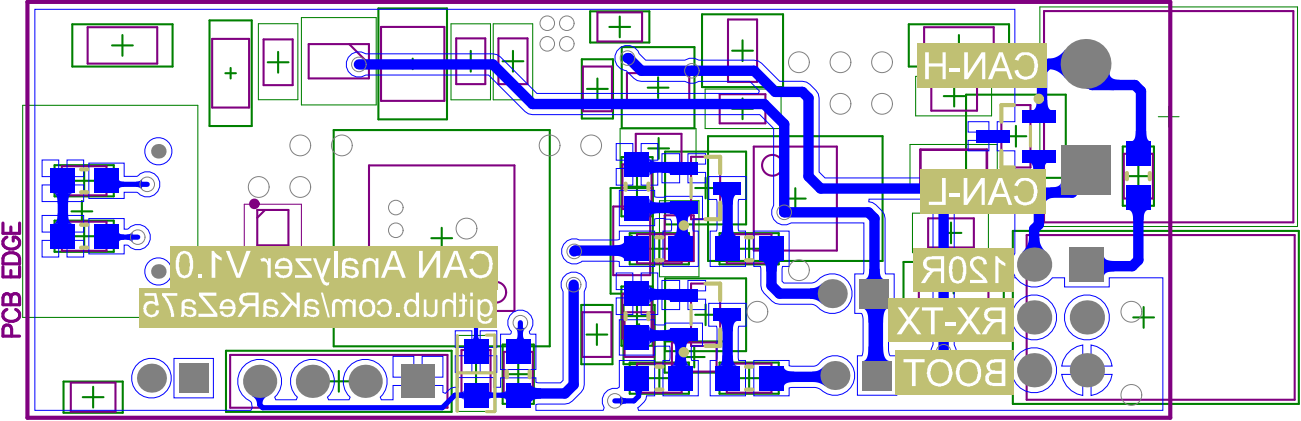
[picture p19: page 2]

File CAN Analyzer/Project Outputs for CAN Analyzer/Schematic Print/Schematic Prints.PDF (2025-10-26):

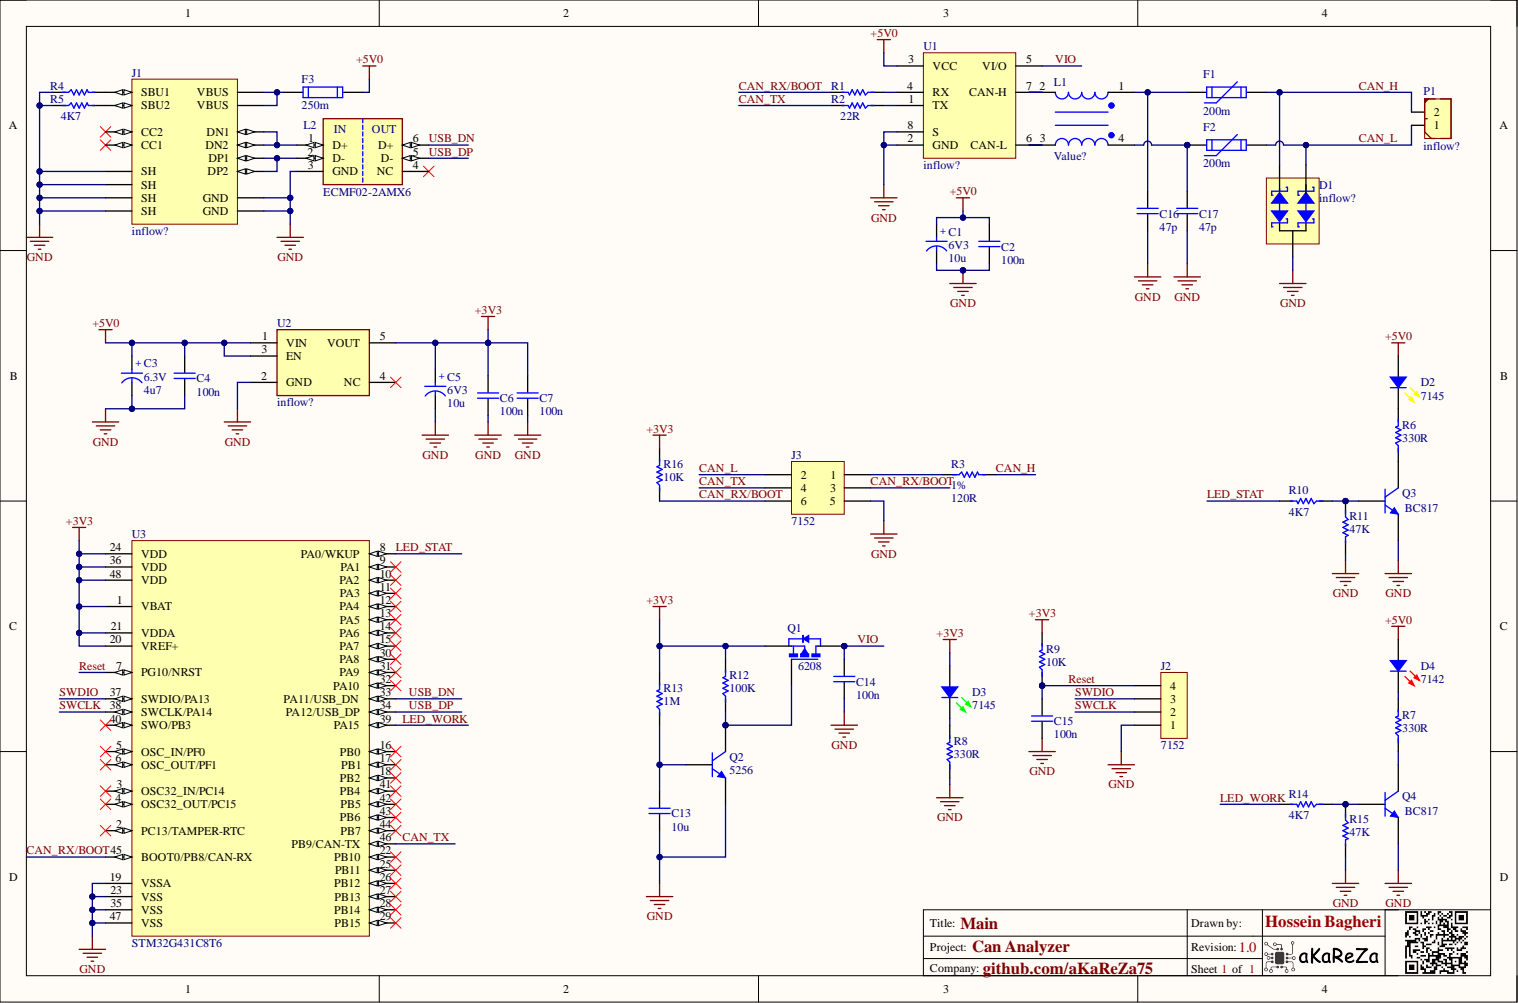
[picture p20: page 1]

Project: Can Analyzer | Revision: 1.0

Company: github.com/aKaReZa75 | Sheet 1 of 1


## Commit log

2025-10-12 Schematic Done!
    [CAN Analyzer.PrjPcb, Sheet1.SchDoc]
2025-10-12 component placment done
    [CAN Analyzer.PrjPcb, PCB.PcbDoc, Sheet1.SchDoc]
2025-10-12 do some routing
    [CAN Analyzer.PrjPcb, PCB.PcbDoc, Sheet1.SchDoc]
2025-10-13 Routing Done!
    [CAN Analyzer.PrjPcb, PCB.PcbDoc]
2025-10-13 add Output Job file
    [CAN Analyzer.PrjPcb]
2025-10-13 add Shopping Link
    [PCB.PcbDoc, Sheet1.SchDoc]
2025-10-13 udpate PCB
    [PCB.PcbDoc, Sheet1.SchDoc]
2025-10-13 rearrange designator
    [PCB.PcbDoc]
2025-10-13 Update prog connector
    [PCB.PcbDoc, Sheet1.SchDoc]
2025-10-26 add files and documents
    [CAN Analyzer.PrjPcb, PCB.PcbDoc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]
2026-09-15 Change CC1&CC2 Connections
    [PCB.PcbDoc, Sheet1.SchDoc]
